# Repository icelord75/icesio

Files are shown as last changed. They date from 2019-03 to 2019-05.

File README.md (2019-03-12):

# iceSIO
iceSIO replacement board for CASIO 3208 modules (CA-53, CA-506 watches)

## Hardware
* MCU: Microchip **PIC16F19197** - 8bit MCU, 56kB flash, 4K RAM, 256b EEPROM
* EEPROM: Microchip **24CW1280T-I/CS0668** - 16KB, WLCSP package
* Accelerometer: NXP **MMA8451QT** - 3-axis, 14-bit/8-bit digital accelerometer
* Compass: Honeywell **HMC5883L** or Isentek **IST8310** - 3-Axis Digital Compass
* Environment: BOSCH **BME280** - Digital humidity, pressure and temperature sensor
* LED:
  * ON Semiconductor **NCP5623CMUTBG** - Triple Output I2C Controlled RGB LED Driver
  * Songxin **SX-0402-RGB** - SMD fullcolor RGB SMD0404 LED
* Battery: **CR2016** -> CR2020 / CR2025 / CR2320 upgradable?

## Features
* TTL 19200bps UART for debug and evolution.
* RTCC for timekeeping.

## Pictures
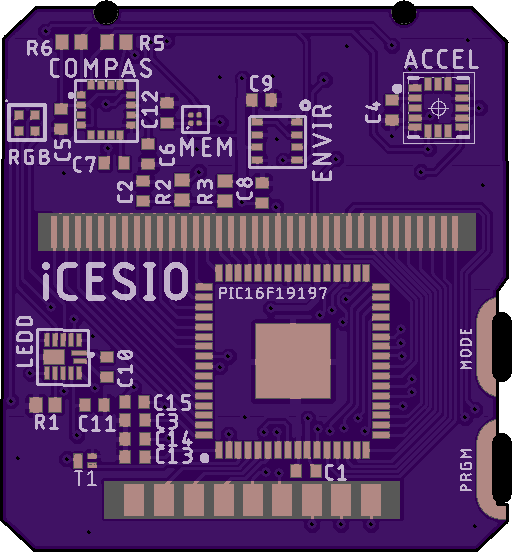
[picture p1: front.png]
front


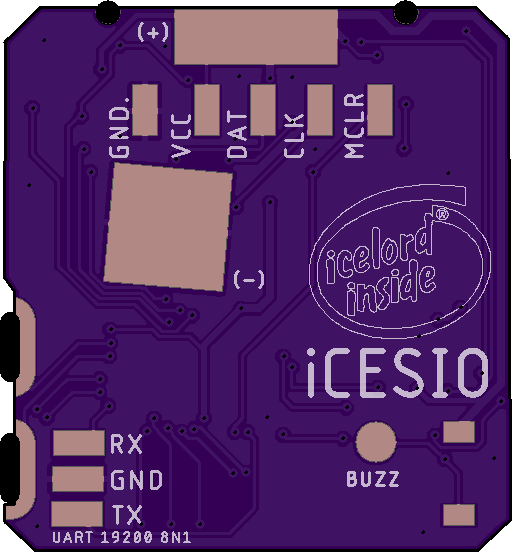
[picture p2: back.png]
back


## TODO Features
* Controls: 2 side buttons + 4*4 keypad
* Timekeeping: Home and World time with automatic DST and assisted calibration
* Perpetual calendar: up to year 2199
* Calculator: Infix, Prefix or Reverse Polish notation (configurable), -9.999999*1099 — +9.9999999*1099 (visual 8 digits mantissa)
* Alarm: 5 daily alarms + 5 weekly alarms + hour signal
* Start/Stop watch: 5 stopwatches up to 23:59:59.59 with 0.01 second resolution
* Timer: 5 countdown timers up to 99:59:59 with 1 second resolution
* Signal: Ring Tone Text Transfer Language (RTTTL) alarm and timer signals
* Minute repeater: audibly chimes the hours and minutes.
* BackLight: full RGB backlight, alarm and timers (configured separately) lights
* Sun: Sunrise and Sunset (Latitude presets + timezone)
* Moon: Precise Moon phase (icon and date)
* Equation of time
* Accelerometer:
  * tap-sensing control
  * tilt sensor
  * speedometer
  * continuous accelerometer
  * 0-100kmh acceleration/deceleration
* Compass:
  * Regular compass
  * Angle finder
* Enviromental sensor:
  * Current temperature (C°/F°)
  * Tranding temperature - hour/12h/24h
  * Current Humidity (%)
  * Tranding humidity - hour/12h/24h
  * Current Barometer (hPA, mBar, at, atm, Torr, mmHg, PSI, inHg)
  * Tranding barometer - hour/12h/24h

## Related Projects
[goodwatch](https://github.com/travisgoodspeed/goodwatch) replacement circuit board for the Casio 3208 module, used in the Casio CA-53W and CA-506 calculator watches.

[Pluto](https://github.com/carrotIndustries/pluto) is a replacement PCB for the Casio F-91W that is also based on an MSP430.

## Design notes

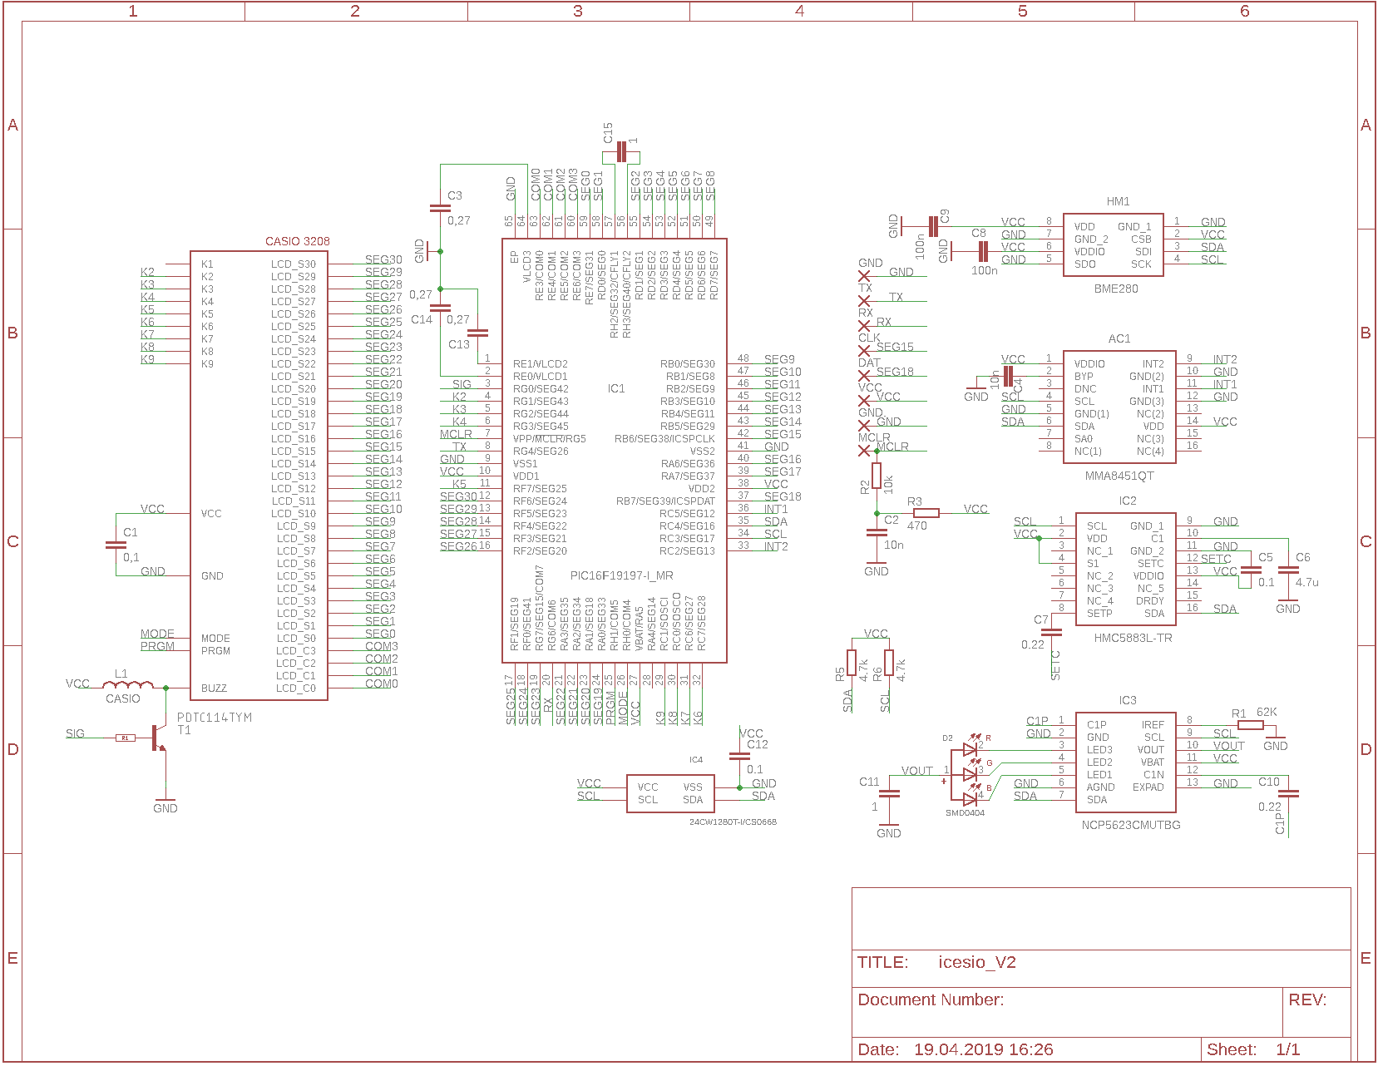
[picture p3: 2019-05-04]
schematic.png

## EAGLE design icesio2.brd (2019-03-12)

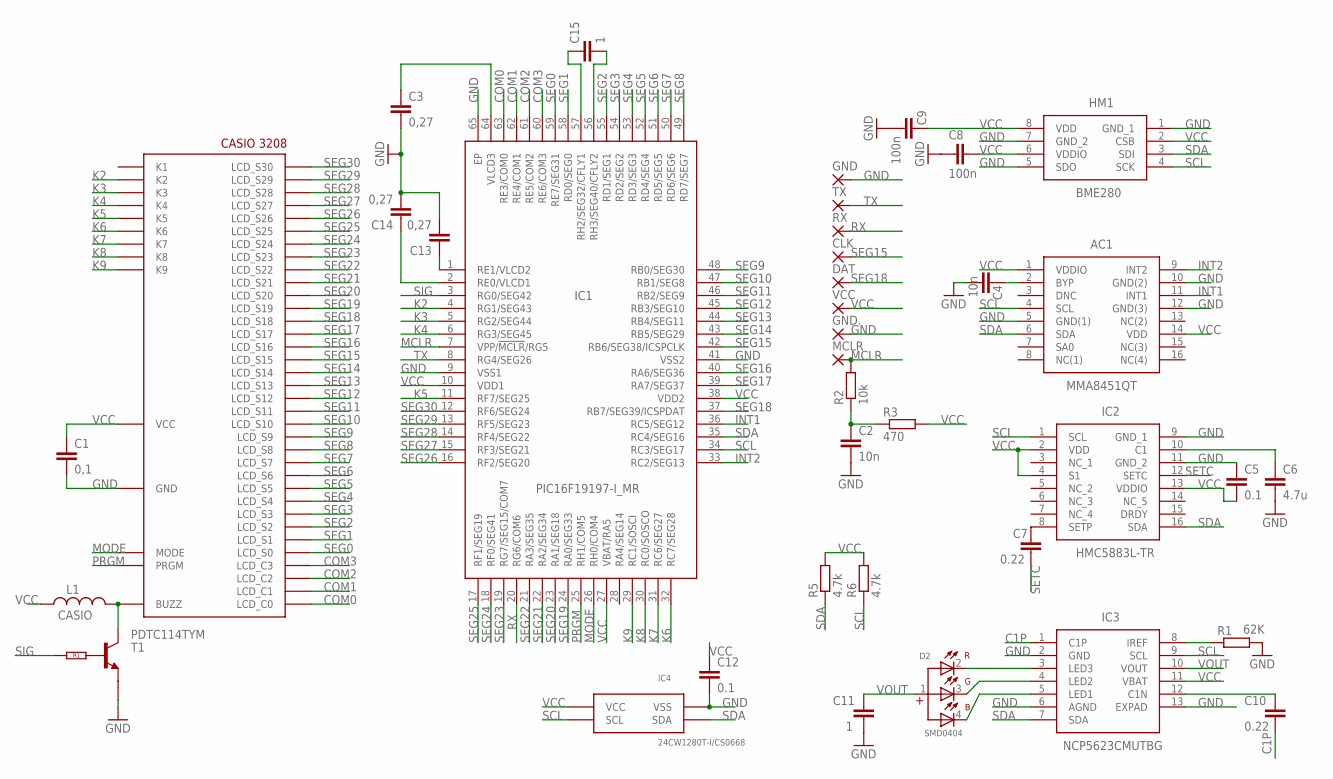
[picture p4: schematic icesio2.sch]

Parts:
AC1: MMA8451QT; PQFN50P300X300X100-16N
C1: 0,1; RESC0402_L
C2, C4: 10n; RESC0402_L
C3, C13, C14: 0,27; RESC0402_L
C5, C12: 0.1; RESC0402_L
C6: 4.7u; RESC0402_L
C7, C10: 0.22; RESC0402_L
C8, C9: 100n; RESC0402_L
C11, C15: 1; RESC0402_L
CLK: WIREPADSMD1,27-254; SMD1,27-2,54
D2: SMD0404; WL-SFCC_0404
DAT: WIREPADSMD1,27-254; SMD1,27-2,54
GND, GND.: WIREPADSMD1,27-254; SMD1,27-2,54
HM1: BME280
IC1: PIC16F19197-I_MR; QFN50P900X900X100-65N
IC2: HMC5883L-TR; 16-PIN-LPCC
IC3: NCP5623CMUTBG; NCP5623BMUTBG
IC4: 24CW1280T-I/CS0668; CSP
L1: CASIO; L4516C
MCLR: WIREPADSMD1,27-254; SMD1,27-2,54
R1: 62K; R0402
R2: 10k; R0402
R3: 470; R0402
R5, R6: 4.7k; R0402
RX: WIREPADSMD1,27-254; SMD1,27-2,54
T1: PDTC114TYM; SOT883(B)
TX: WIREPADSMD1,27-254; SMD1,27-2,54
U$1: CASIO3208
VCC: WIREPADSMD1,27-254; SMD1,27-2,54

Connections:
BUZ: L1.2, T1.3 (C), U$1.BUZZ
BYP: AC1.2 (BYP), C4.1
C1: C6.1, IC2.10 (C1)
C1P: C10.2, IC3.1 (C1P)
CFLY1: C15.1, IC1.57 (RH2/SEG32/CFLY1)
CFLY2: C15.2, IC1.56 (RH3/SEG40/CFLY2)
COM0: IC1.63 (RE3/COM0), U$1.LCD1 (LCD_C0)
COM1: IC1.62 (RE4/COM1), U$1.LCD2 (LCD_C1)
COM2: IC1.61 (RE5/COM2), U$1.LCD3 (LCD_C2)
COM3: IC1.60 (RE6/COM3), U$1.LCD4 (LCD_C3)
GND: AC1.5 (GND(1)), AC1.10 (GND(2)), AC1.12 (GND(3)), C1.2, C2.2, C3.2, C4.2, C5.1, C6.2, C8.2, C9.2, C11.2, C12.2, C13.2, C14.2, GND.1, GND..1, HM1.1 (GND_1), HM1.5 (SDO), HM1.7 (GND_2), IC1.9 (VSS1), IC1.41 (VSS2), IC1.65 (EP), IC2.9 (GND_1), IC2.11 (GND_2), IC3.2 (GND), IC3.6 (AGND), IC3.13 (EXPAD), IC4.VSS, R1.2, T1.2 (E), U$1.GND
INT1: AC1.11 (INT1), IC1.36 (RC5/SEG12)
INT2: AC1.9 (INT2), IC1.33 (RC2/SEG13)
K2: IC1.4 (RG1/SEG43), U$1.K2
K3: IC1.5 (RG2/SEG44), U$1.K3
K4: IC1.6 (RG3/SEG45), U$1.K4
K5: IC1.11 (RF7/SEG25), U$1.K5
K6: IC1.32 (RC7/SEG28), U$1.K6
K7: IC1.31 (RC6/SEG27), U$1.K7
K8: IC1.30 (RC0/SOSCO), U$1.K8
K9: IC1.29 (RC1/SOSCI), U$1.K9
MCLR: IC1.7 (VPP/!MCLR!/RG5), MCLR.1, R2.2
MCLRVCC: C2.1, R2.1, R3.1
MODE: IC1.26 (RH0/COM4), U$1.MODE
unnamed: D2.2 (R), IC3.3 (LED3)
unnamed: C7.1, IC2.8 (SETP)
unnamed: D2.3 (G), IC3.4 (LED2)
unnamed: D2.4 (B), IC3.5 (LED1)
unnamed: IC3.8 (IREF), R1.1
unnamed: C10.1, IC3.12 (C1N)
PRGM: IC1.25 (RH1/COM5), U$1.PRGM
RX: IC1.20 (RG6/COM6), RX.1
SCL: AC1.4 (SCL), HM1.4 (SCK), IC1.34 (RC3/SEG17), IC2.1 (SCL), IC3.9 (SCL), IC4.SCL, R6.1
SDA: AC1.6 (SDA), HM1.3 (SDI), IC1.35 (RC4/SEG16), IC2.16 (SDA), IC3.7 (SDA), IC4.SDA, R5.1
SEG0: IC1.59 (RE7/SEG31), U$1.LCD5 (LCD_S0)
SEG1: IC1.58 (RD0/SEG0), U$1.LCD6 (LCD_S1)
SEG2: IC1.55 (RD1/SEG1), U$1.LCD7 (LCD_S2)
SEG3: IC1.54 (RD2/SEG2), U$1.LCD8 (LCD_S3)
SEG4: IC1.53 (RD3/SEG3), U$1.LCD9 (LCD_S4)
SEG5: IC1.52 (RD4/SEG4), U$1.LCD10 (LCD_S5)
SEG6: IC1.51 (RD5/SEG5), U$1.LCD11 (LCD_S6)
SEG7: IC1.50 (RD6/SEG6), U$1.LCD12 (LCD_S7)
SEG8: IC1.49 (RD7/SEG7), U$1.LCD13 (LCD_S8)
SEG9: IC1.48 (RB0/SEG30), U$1.LCD14 (LCD_S9)
SEG10: IC1.47 (RB1/SEG8), U$1.LCD15 (LCD_S10)
SEG11: IC1.46 (RB2/SEG9), U$1.LCD16 (LCD_S11)
SEG12: IC1.45 (RB3/SEG10), U$1.LCD17 (LCD_S12)
SEG13: IC1.44 (RB4/SEG11), U$1.LCD18 (LCD_S13)
SEG14: IC1.43 (RB5/SEG29), U$1.LCD19 (LCD_S14)
SEG15: CLK.1, IC1.42 (RB6/SEG38/ICSPCLK), U$1.LCD20 (LCD_S15)
SEG16: IC1.40 (RA6/SEG36), U$1.LCD21 (LCD_S16)
SEG17: IC1.39 (RA7/SEG37), U$1.LCD22 (LCD_S17)
SEG18: DAT.1, IC1.37 (RB7/SEG39/ICSPDAT), U$1.LCD23 (LCD_S18)
SEG19: IC1.24 (RA0/SEG33), U$1.LCD24 (LCD_S19)
SEG20: IC1.23 (RA1/SEG18), U$1.LCD25 (LCD_S20)
SEG21: IC1.22 (RA2/SEG34), U$1.LCD26 (LCD_S21)
SEG22: IC1.21 (RA3/SEG35), U$1.LCD27 (LCD_S22)
SEG23: IC1.19 (RG7/SEG15/COM7), U$1.LCD28 (LCD_S23)
SEG24: IC1.18 (RF0/SEG41), U$1.LCD29 (LCD_S24)
SEG25: IC1.17 (RF1/SEG19), U$1.LCD30 (LCD_S25)
SEG26: IC1.16 (RF2/SEG20), U$1.LCD31 (LCD_S26)
SEG27: IC1.15 (RF3/SEG21), U$1.LCD32 (LCD_S27)
SEG28: IC1.14 (RF4/SEG22), U$1.LCD33 (LCD_S28)
SEG29: IC1.13 (RF5/SEG23), U$1.LCD34 (LCD_S29)
SEG30: IC1.12 (RF6/SEG24), U$1.LCD35 (LCD_S30)
SETC: C7.2, IC2.12 (SETC)
SIG: IC1.3 (RG0/SEG42), T1.1 (INPUT)
TX: IC1.8 (RG4/SEG26), TX.1
VCC: AC1.1 (VDDIO), AC1.14 (VDD), C1.1, C5.2, C8.1, C9.1, C12.1, HM1.2 (CSB), HM1.6 (VDDIO), HM1.8 (VDD), IC1.10 (VDD1), IC1.27 (VBAT/RA5), IC1.38 (VDD2), IC2.2 (VDD), IC2.4 (S1), IC2.13 (VDDIO), IC3.11 (VBAT), IC4.VCC, L1.1, R3.2, R5.2, R6.2, U$1.VCC, VCC.1
VLCD1: C14.1, IC1.2 (RE0/VLCD1)
VLCD2: C13.1, IC1.1 (RE1/VLCD2)
VLCD3: C3.1, IC1.64 (VLCD3)
VOUT: C11.1, D2.1, IC3.10 (VOUT)

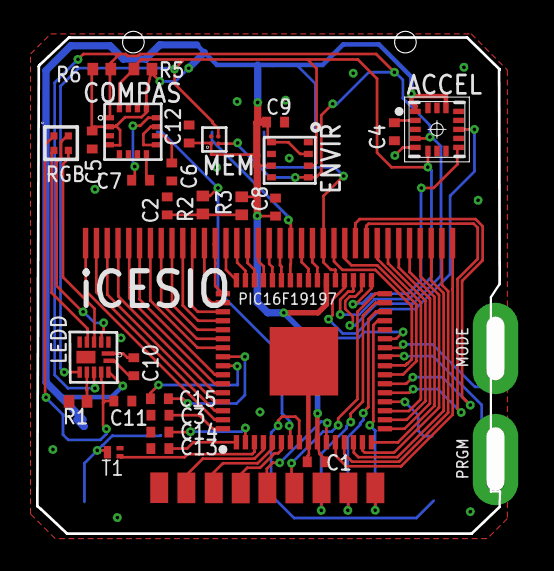
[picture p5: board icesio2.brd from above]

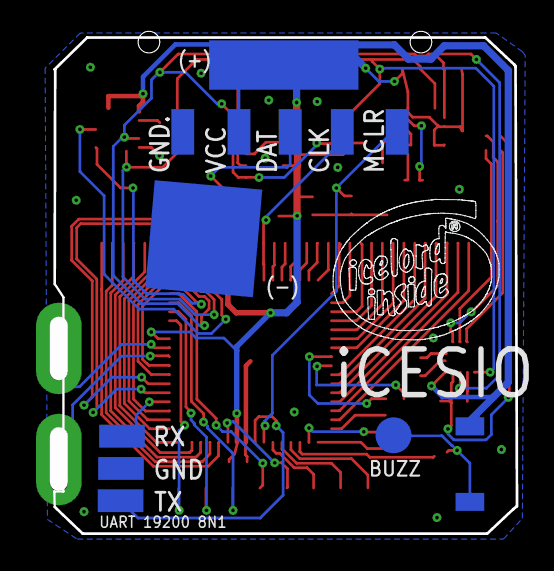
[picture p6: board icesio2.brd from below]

Board: 2 copper layers, 25.7 x 27.6 mm, 39 parts (10 on the bottom side), 73 nets.

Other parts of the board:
U$2: ICELORD_SMALL

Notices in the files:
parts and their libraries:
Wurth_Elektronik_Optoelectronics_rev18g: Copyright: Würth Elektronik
